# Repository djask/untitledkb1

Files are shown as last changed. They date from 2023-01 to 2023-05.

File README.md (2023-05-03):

 # UntitledKb1

 A 5x14 ortholinear board with an STM32 Blackpill. USB port is removed and rotated to face the back, which avoids any issues with trying to fit a usb cable sideways. This board  needs a decent amount of SMD soldering experience for the diodes and USB-C port resistors. 
 
 ## BOM
 - STM32 Blackpill or similar footprint
 - 1x PCB and FR4 plate
 - 40 socket pins and spare through hole wires to socket the STM32
 - 1 Acrylic base cut
 - 2x 5.1k resistors 0402 (can take from stm32 blackpill)
 - 1x 0ohm resistor (optional, just solder copper wire over the pads)
 - 70 Diodes (depends on key count)
 - 70 MX Switches
 - 7mm spacers + some more spacers for the 2nd acrylic panel
 - m2x8 or m2x10 screws x4 (top plate)
 - m2x5 to m2x8 screws x5 (bottom part of plate)
 - Rubber feet (optional)
 - Stabilizers (optional)
 
## Software
See https://github.com/djask/qmk_defs/tree/master/untitledkb1 for a QMK reference config. The board, however, is compatible with any software that supports ARM microcontrollers. 




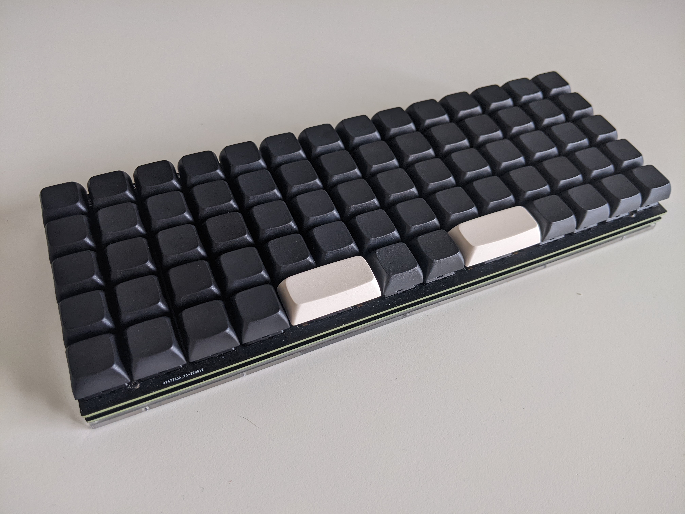
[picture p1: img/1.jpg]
 
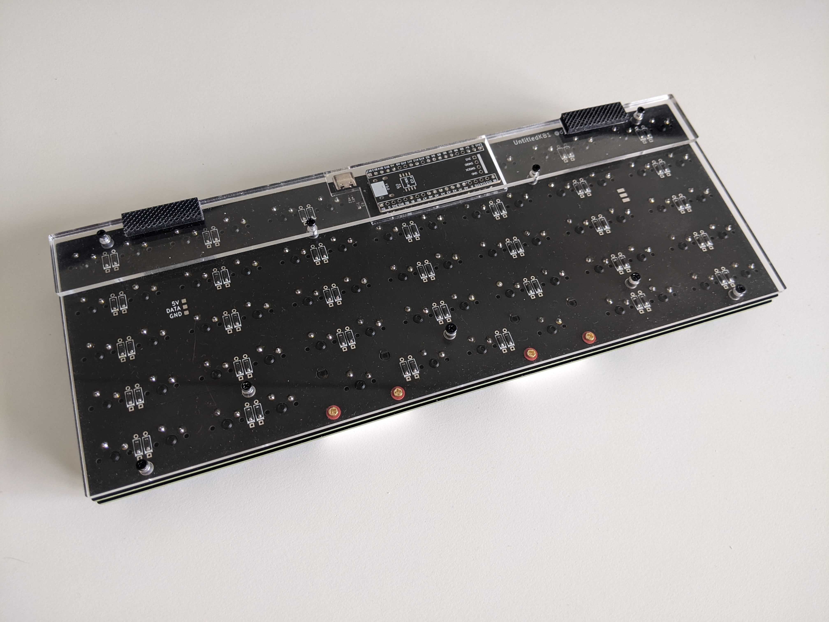
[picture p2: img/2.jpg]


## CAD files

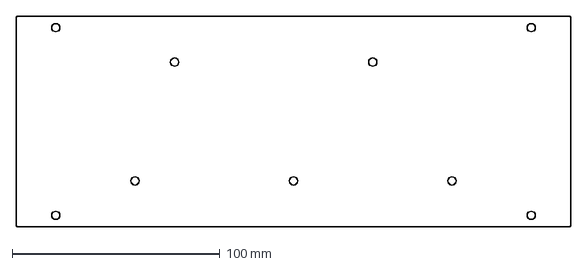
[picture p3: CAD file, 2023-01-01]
2-pcboutline.dxf
266.7 x 101.2 mm

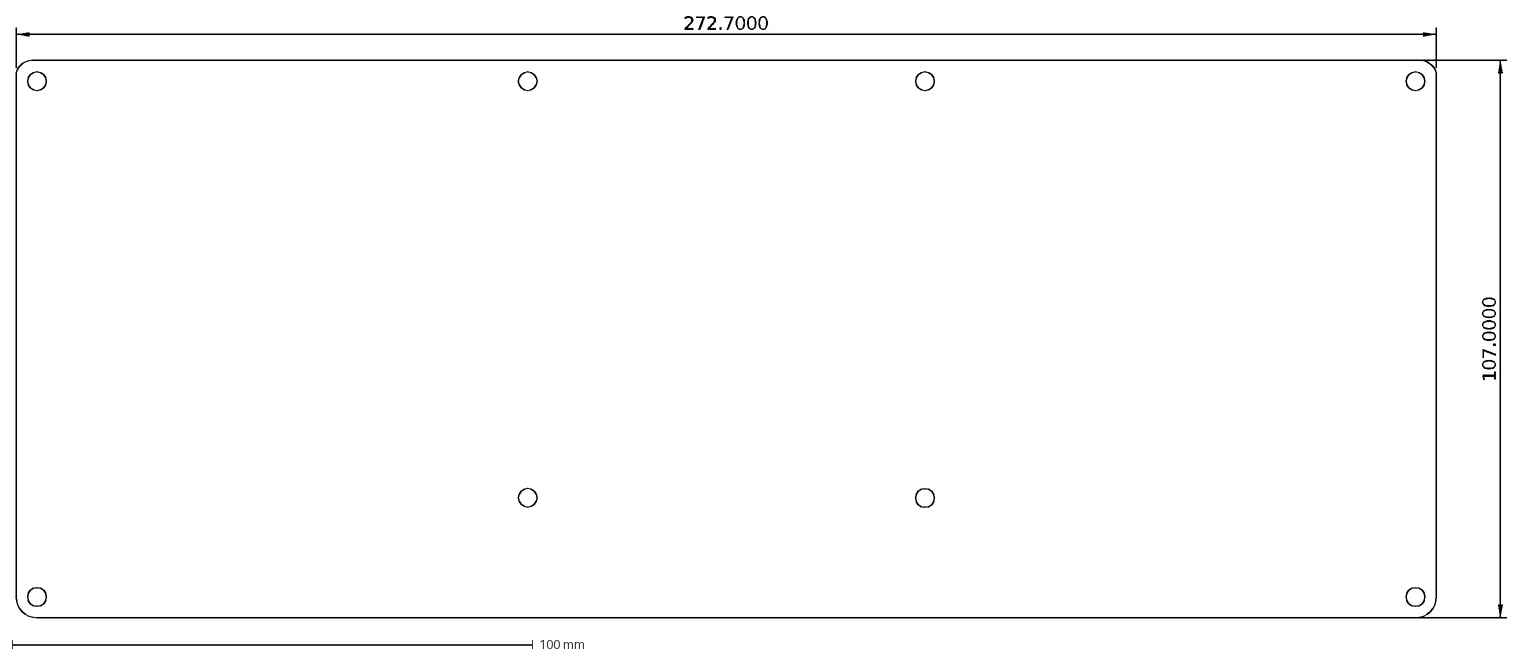
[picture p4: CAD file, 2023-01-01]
kicad-pcb/pcb.dxf
272.7000
107.0000

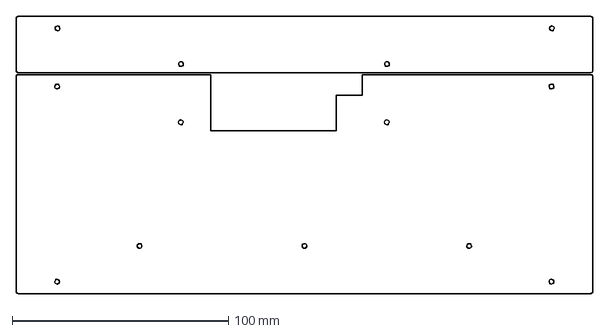
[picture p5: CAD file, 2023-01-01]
3-acrylic-cut.dxf
266.8 x 128.1 mm

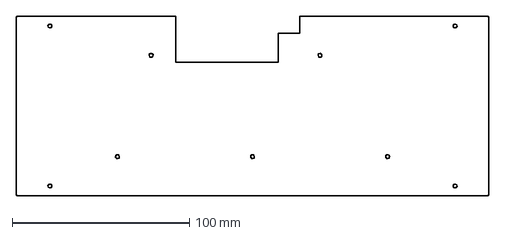
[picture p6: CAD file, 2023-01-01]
3.1-base1.dxf
266.7 x 101.3 mm

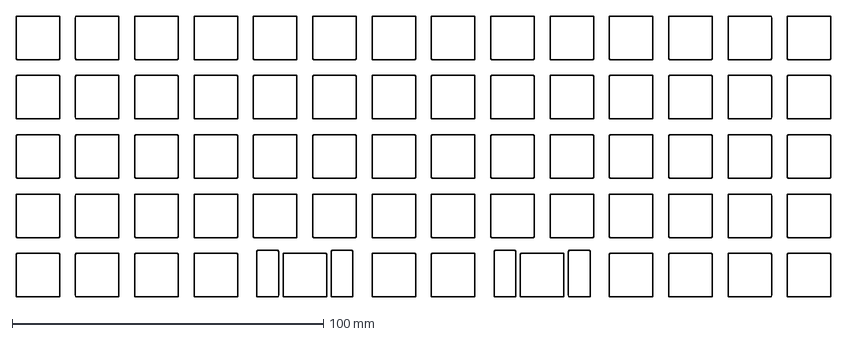
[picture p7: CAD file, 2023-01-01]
kbplate.dxf
261.7 x 90.2 mm

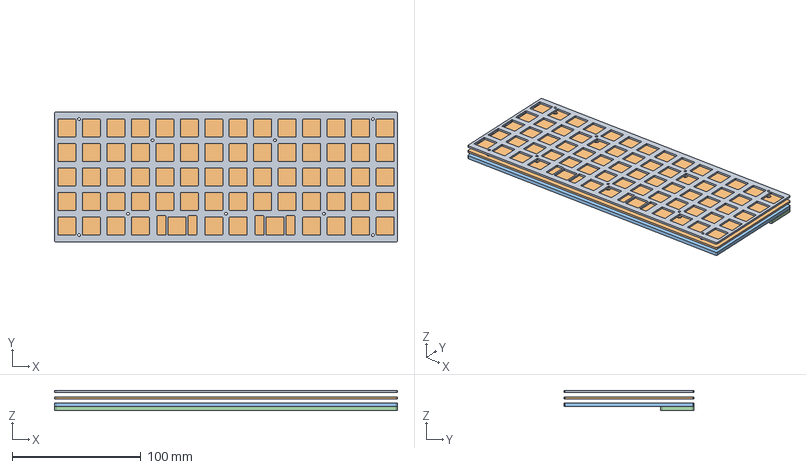
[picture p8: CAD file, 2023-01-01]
kb.step
266.8 x 101.3 x 15.6 mm
cf729e6c-3214-11ed-adba-52540033f8d7_part
plate_part
pcb_part
b1_part
b2_part

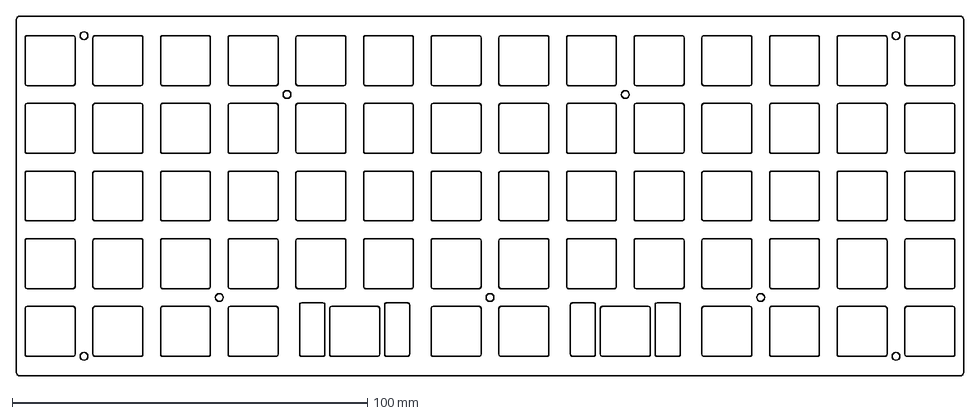
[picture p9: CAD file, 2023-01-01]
1-plate.dxf
266.7 x 101.2 mm

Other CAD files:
0-fc-exports.FCStd

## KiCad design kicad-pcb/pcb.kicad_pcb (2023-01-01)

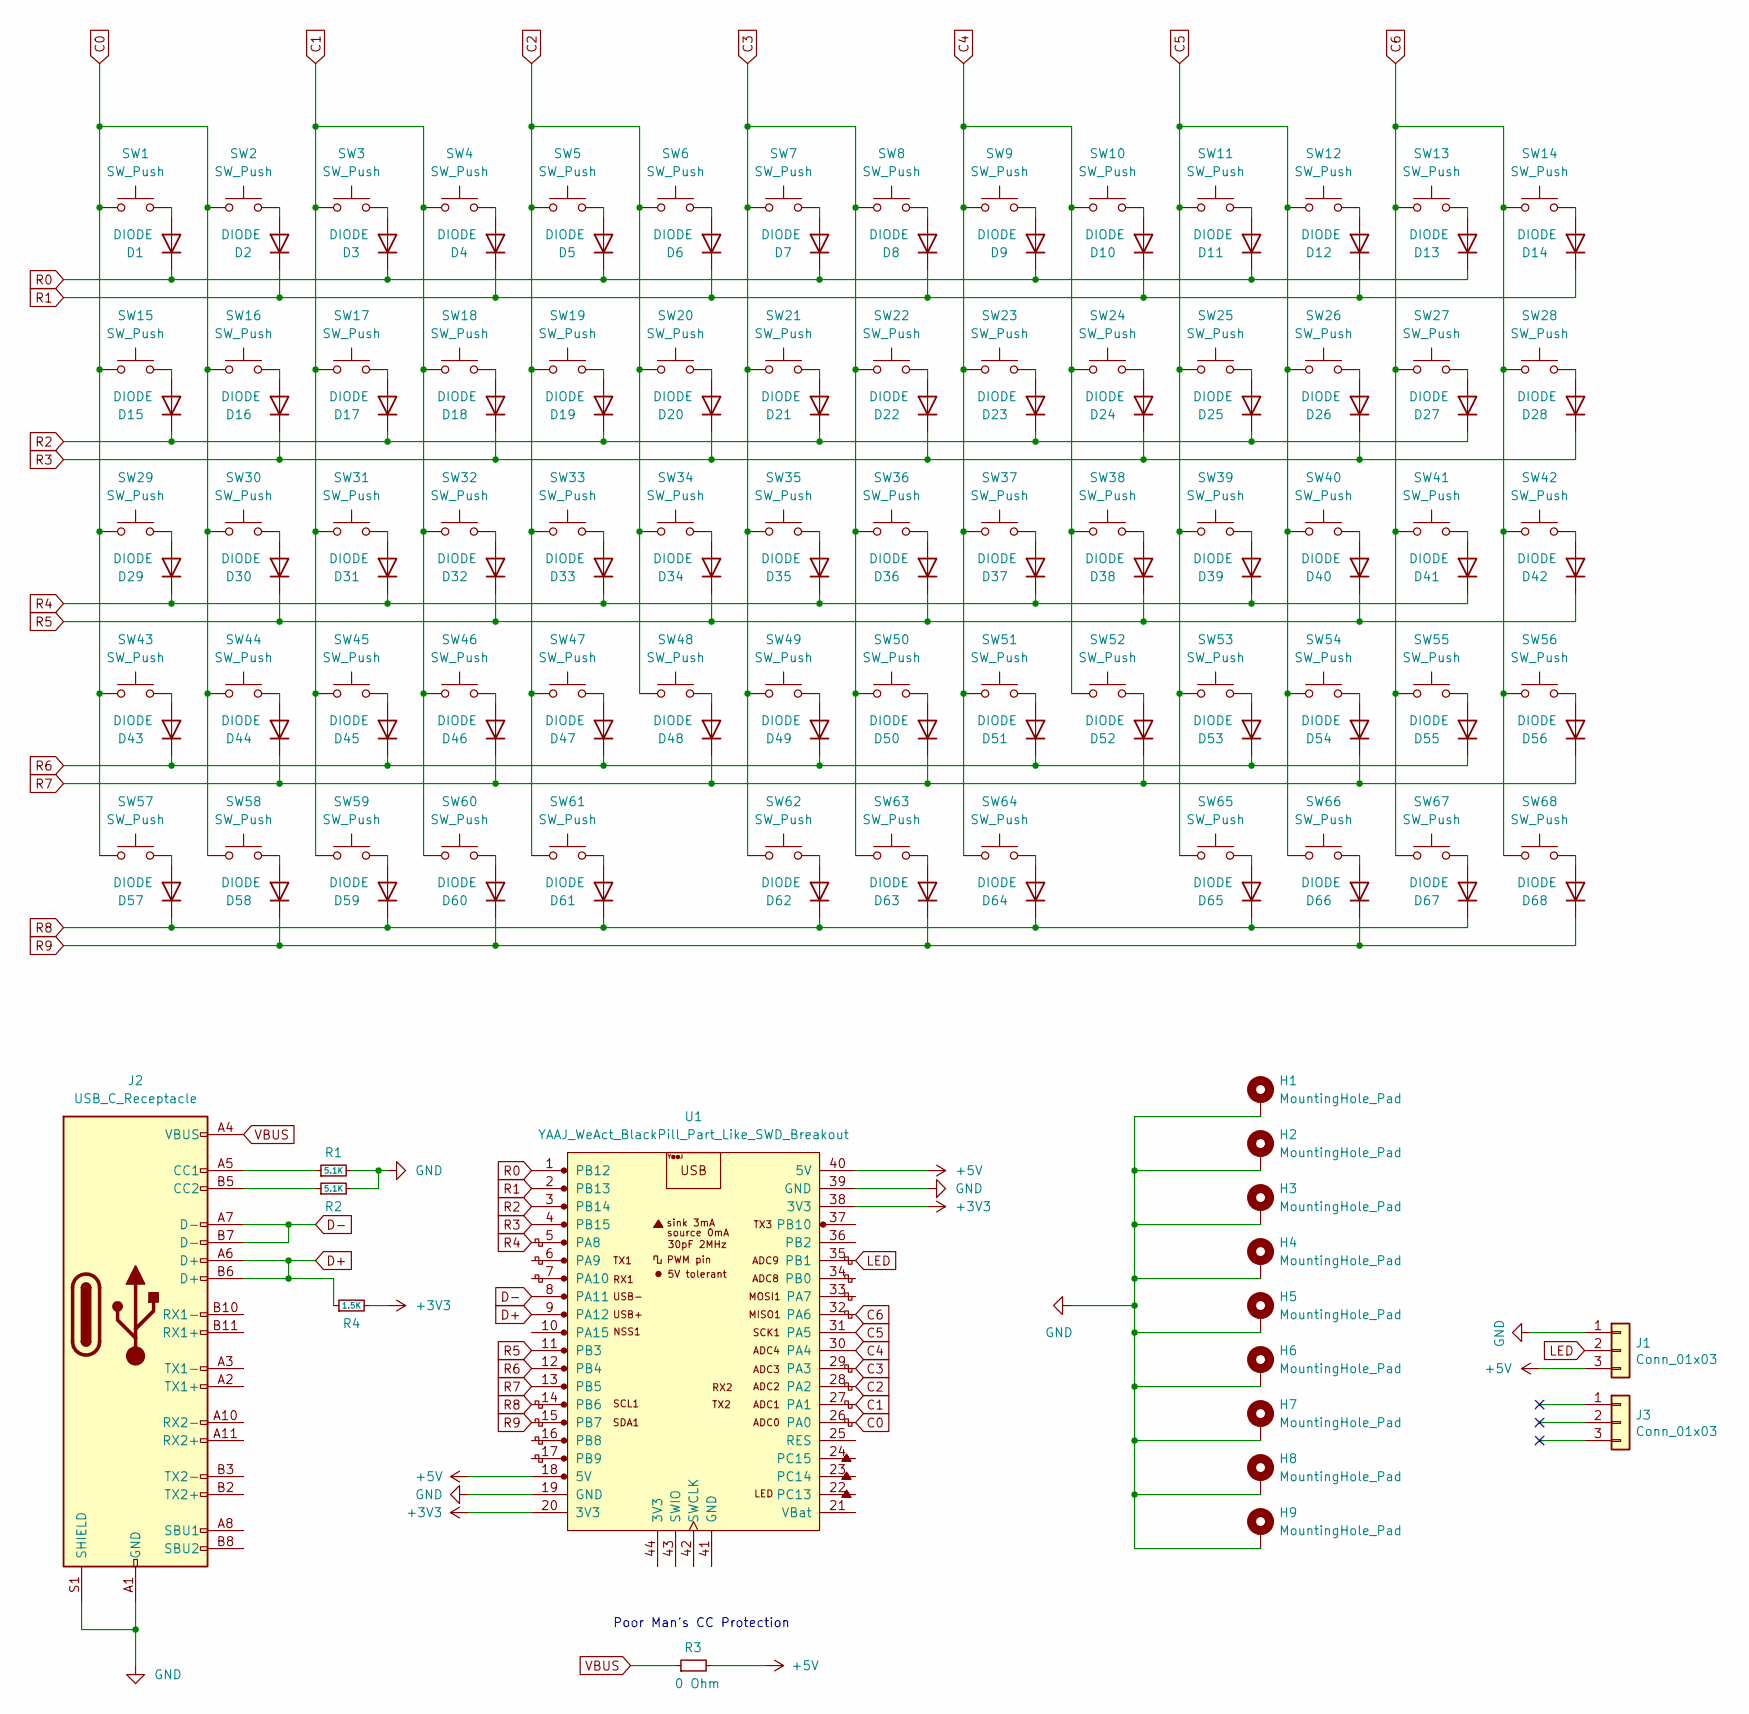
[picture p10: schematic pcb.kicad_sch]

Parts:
D1, D2, D3, D4, D5, D6, D7, D8, D9, D10, D11, D12, D13, D14, D15, D16, D17, D18, D19, D20, D21, D22, D23, D24, D25, D26, D27, D28, D29, D30, D31, D32, D33, D34, D35, D36, D37, D38, D39, D40, D41, D42, D43, D44, D45, D46, D47, D48, D49, D50, D51, D52, D53, D54, D55, D56, D57, D58, D59, D60, D61, D62, D63, D64, D65, D66, D67, D68: DIODE; D_SOD123_axial
H1, H2, H3, H4, H5, H6, H7, H8, H9: MountingHole_Pad; Mounting_Hole
J1, J3: Conn_01x03; StripLED_front
J2: USB_C_Receptacle; USB_C_Receptacle_Palconn_UTC16-G
R1, R2: 5.1K; R_0402_1005Metric_Pad0.72x0.64mm_HandSolder
R3: 0 Ohm
R4: 1.5K; R_0402_1005Metric_Pad0.72x0.64mm_HandSolder
SW1, SW2, SW3, SW4, SW5, SW6, SW7, SW8, SW9, SW10, SW11, SW12, SW13, SW14, SW15, SW16, SW17, SW18, SW19, SW20, SW21, SW22, SW23, SW24, SW25, SW26, SW27, SW28, SW29, SW30, SW31, SW32, SW33, SW34, SW35, SW36, SW37, SW38, SW39, SW40, SW41, SW42, SW43, SW44, SW45, SW46, SW47, SW48, SW49, SW50, SW51, SW52, SW53, SW54, SW55, SW56, SW57, SW58, SW59, SW60, SW62, SW63, SW65, SW66, SW67, SW68: SW_Push; MXOnly-1U-NoLED
SW61, SW64: SW_Push; MXOnly-2U-ReversedStabilizers-NoLED
U1: YAAJ_WeAct_BlackPill_Part_Like_SWD_Breakout; YAAJ_WeAct_BlackPill_2

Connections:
+3V3: R4.2, U1.20 (3V3), U1.38 (3V3)
+5V: J1.3, R3.2, U1.18 (5V), U1.40 (5V)
C0: SW1.1, SW2.1, SW15.1, SW16.1, SW29.1, SW30.1, SW43.1, SW44.1, SW57.1, SW58.1, U1.26 (PA0)
C1: SW3.1, SW4.1, SW17.1, SW18.1, SW31.1, SW32.1, SW45.1, SW46.1, SW59.1, SW60.1, U1.27 (PA1)
C2: SW5.1, SW6.1, SW19.1, SW20.1, SW33.1, SW34.1, SW47.1, SW48.1, SW61.1, U1.28 (PA2)
C3: SW7.1, SW8.1, SW21.1, SW22.1, SW35.1, SW36.1, SW49.1, SW50.1, SW62.1, SW63.1, U1.29 (PA3)
C4: SW9.1, SW10.1, SW23.1, SW24.1, SW37.1, SW38.1, SW51.1, SW52.1, SW64.1, U1.30 (PA4)
C5: SW11.1, SW12.1, SW25.1, SW26.1, SW39.1, SW40.1, SW53.1, SW54.1, SW65.1, SW66.1, U1.31 (PA5)
C6: SW13.1, SW14.1, SW27.1, SW28.1, SW41.1, SW42.1, SW55.1, SW56.1, SW67.1, SW68.1, U1.32 (PA6)
D+: J2.A6 (D+), J2.B6 (D+), R4.1, U1.9 (PA12)
D-: J2.A7 (D-), J2.B7 (D-), U1.8 (PA11)
GND: H1.1, H2.1, H3.1, H4.1, H5.1, H6.1, H7.1, H8.1, H9.1, J1.1, J2.A1 (GND), J2.A12 (GND), J2.B1 (GND), J2.B12 (GND), J2.S1 (SHIELD), R1.2, R2.2, U1.19 (GND), U1.39 (GND)
LED: J1.2, U1.35 (PB1)
unnamed: D1.2 (A), SW1.2
unnamed: D2.2 (A), SW2.2
unnamed: D3.2 (A), SW3.2
unnamed: D4.2 (A), SW4.2
unnamed: D5.2 (A), SW5.2
unnamed: D6.2 (A), SW6.2
unnamed: D7.2 (A), SW7.2
unnamed: D8.2 (A), SW8.2
unnamed: D9.2 (A), SW9.2
unnamed: D10.2 (A), SW10.2
unnamed: D11.2 (A), SW11.2
unnamed: D12.2 (A), SW12.2
unnamed: D13.2 (A), SW13.2
unnamed: D14.2 (A), SW14.2
unnamed: D15.2 (A), SW15.2
unnamed: D16.2 (A), SW16.2
unnamed: D17.2 (A), SW17.2
unnamed: D18.2 (A), SW18.2
unnamed: D19.2 (A), SW19.2
unnamed: D20.2 (A), SW20.2
unnamed: D21.2 (A), SW21.2
unnamed: D22.2 (A), SW22.2
unnamed: D23.2 (A), SW23.2
unnamed: D24.2 (A), SW24.2
unnamed: D25.2 (A), SW25.2
unnamed: D26.2 (A), SW26.2
unnamed: D27.2 (A), SW27.2
unnamed: D28.2 (A), SW28.2
unnamed: D29.2 (A), SW29.2
unnamed: D30.2 (A), SW30.2
unnamed: D31.2 (A), SW31.2
unnamed: D32.2 (A), SW32.2
unnamed: D33.2 (A), SW33.2
unnamed: D34.2 (A), SW34.2
unnamed: D35.2 (A), SW35.2
unnamed: D36.2 (A), SW36.2
unnamed: D37.2 (A), SW37.2
unnamed: D38.2 (A), SW38.2
unnamed: D39.2 (A), SW39.2
unnamed: D40.2 (A), SW40.2
unnamed: D41.2 (A), SW41.2
unnamed: D42.2 (A), SW42.2
unnamed: D43.2 (A), SW43.2
unnamed: D44.2 (A), SW44.2
unnamed: D45.2 (A), SW45.2
unnamed: D46.2 (A), SW46.2
unnamed: D47.2 (A), SW47.2
unnamed: D48.2 (A), SW48.2
unnamed: D49.2 (A), SW49.2
unnamed: D50.2 (A), SW50.2
unnamed: D51.2 (A), SW51.2
unnamed: D52.2 (A), SW52.2
unnamed: D53.2 (A), SW53.2
unnamed: D54.2 (A), SW54.2
unnamed: D55.2 (A), SW55.2
unnamed: D56.2 (A), SW56.2
unnamed: D57.2 (A), SW57.2
unnamed: D58.2 (A), SW58.2
unnamed: D59.2 (A), SW59.2
unnamed: D60.2 (A), SW60.2
unnamed: D61.2 (A), SW61.2
unnamed: D62.2 (A), SW62.2
unnamed: D63.2 (A), SW63.2
unnamed: D64.2 (A), SW64.2
unnamed: D65.2 (A), SW65.2
unnamed: D66.2 (A), SW66.2
unnamed: D67.2 (A), SW67.2
unnamed: D68.2 (A), SW68.2
unnamed: J2.A5 (CC1), R1.1
unnamed: J2.B5 (CC2), R2.1
R0: D1.1 (K), D3.1 (K), D5.1 (K), D7.1 (K), D9.1 (K), D11.1 (K), D13.1 (K), U1.1 (PB12)
R1: D2.1 (K), D4.1 (K), D6.1 (K), D8.1 (K), D10.1 (K), D12.1 (K), D14.1 (K), U1.2 (PB13)
R2: D15.1 (K), D17.1 (K), D19.1 (K), D21.1 (K), D23.1 (K), D25.1 (K), D27.1 (K), U1.3 (PB14)
R3: D16.1 (K), D18.1 (K), D20.1 (K), D22.1 (K), D24.1 (K), D26.1 (K), D28.1 (K), U1.4 (PB15)
R4: D29.1 (K), D31.1 (K), D33.1 (K), D35.1 (K), D37.1 (K), D39.1 (K), D41.1 (K), U1.5 (PA8)
R5: D30.1 (K), D32.1 (K), D34.1 (K), D36.1 (K), D38.1 (K), D40.1 (K), D42.1 (K), U1.11 (PB3)
R6: D43.1 (K), D45.1 (K), D47.1 (K), D49.1 (K), D51.1 (K), D53.1 (K), D55.1 (K), U1.12 (PB4)
R7: D44.1 (K), D46.1 (K), D48.1 (K), D50.1 (K), D52.1 (K), D54.1 (K), D56.1 (K), U1.13 (PB5)
R8: D57.1 (K), D59.1 (K), D61.1 (K), D62.1 (K), D64.1 (K), D65.1 (K), D67.1 (K), U1.14 (PB6)
R9: D58.1 (K), D60.1 (K), D63.1 (K), D66.1 (K), D68.1 (K), U1.15 (PB7)
VBUS: J2.A4 (VBUS), J2.A9 (VBUS), J2.B4 (VBUS), J2.B9 (VBUS), R3.1

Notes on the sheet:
Poor Man's CC Protection

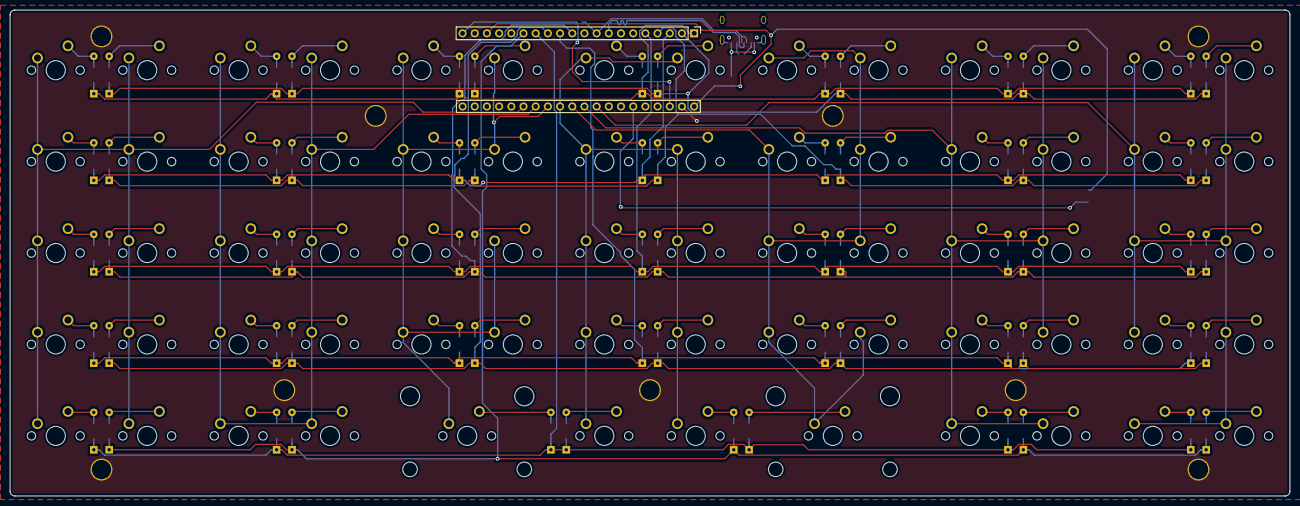
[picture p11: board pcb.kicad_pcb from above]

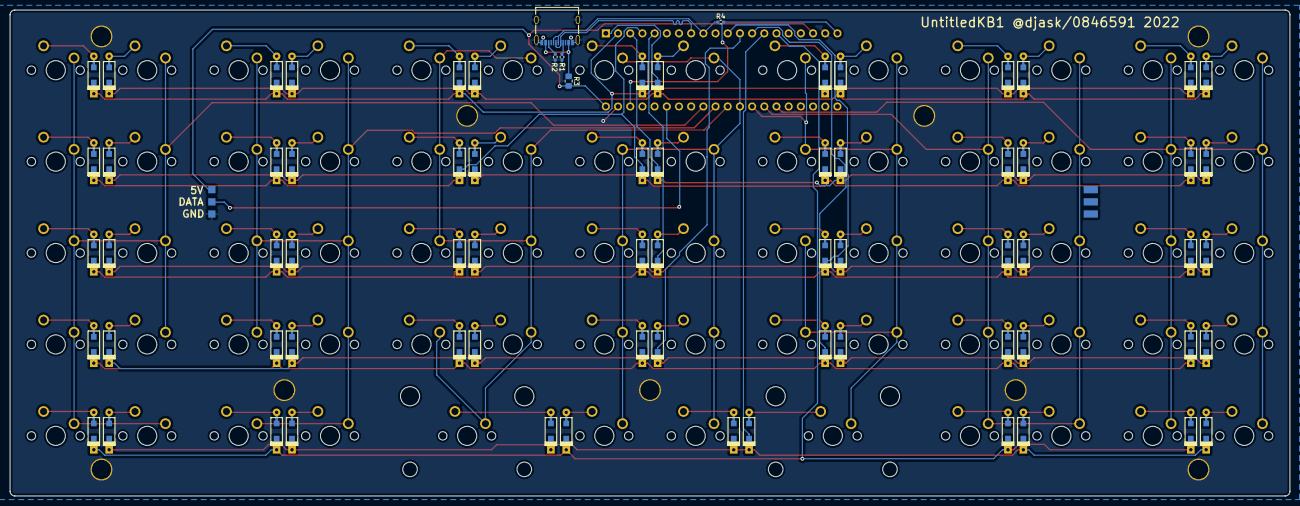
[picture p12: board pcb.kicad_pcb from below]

Board: 2 copper layers, 266.7 x 101.2 mm, 153 parts (75 on the bottom side), 94 nets.
